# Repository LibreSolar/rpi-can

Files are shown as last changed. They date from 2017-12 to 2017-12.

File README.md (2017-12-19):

# Libre Solar CAN interface for Raspberry Pi (Zero W)

**Caution:** Developed using nightly build of KiCAD because of several nice features. Unfortunately, the files are not compatible with the current stable version, but a new compatible stable release (v5) of KiCad is expected soon.

## CAN to Wifi Gateway

This interface PCB allows to read data from the CAN bus connecting the Libre Solar components. So the Raspberry Pi can be used as a gateway to IoT applications and energy monitoring (e.g. using Open Energy Monitor).

The pin header is compatible with all Raspberry Pi models, but the size is especially suited for the Raspberry Pi Zero W.

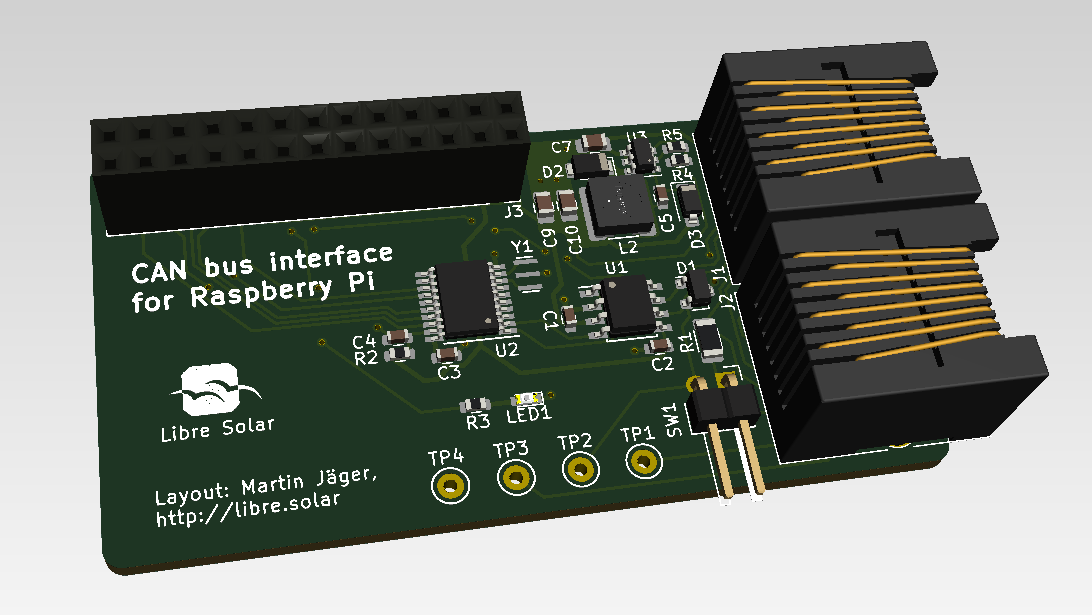
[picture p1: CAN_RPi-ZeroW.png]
Raspberry Pi CAN interface PCB


## Features:
- CAN interface via SPI using MCP2515 controller and TJA1042T/3 transceiver
- Power supply of Raspberry Pi via bus connector (RJ45)
- CAN transceiver standby connected to GPIO 24 (low power consumption mode possible)
- LED on GPIO 22 for custom status information

## Installation

Make sure to install the latest Raspbian onto your Raspberry Pi and connecto to it via SSH.

In order to activate the MCP2515 CAN controller, add the following lines to the file */boot/config.txt*:

```
# MCP 2515 CAN controller
dtparam=spi=on
dtoverlay=mcp2515-can0,oscillator=8000000,interrupt=25
```

Other guides for CAN on Raspberry Pi still suggest to add a line *dtoverlay=spi-bcm2835-overlay*. This is not true anymore, as Raspbian loads the BCM2835 SPI driver automatically.

Bring the interface up with the following command (change bitrate according to your needs):

```
sudo ip link set can0 up type can bitrate 250000
```

Now you should be able to send some test messages with *cansend* or watch messages on the bus:

```
candump can0
```

If something went wrong, try the following command to get some information about the CAN interface:

```
ip -s -d link show can0
```

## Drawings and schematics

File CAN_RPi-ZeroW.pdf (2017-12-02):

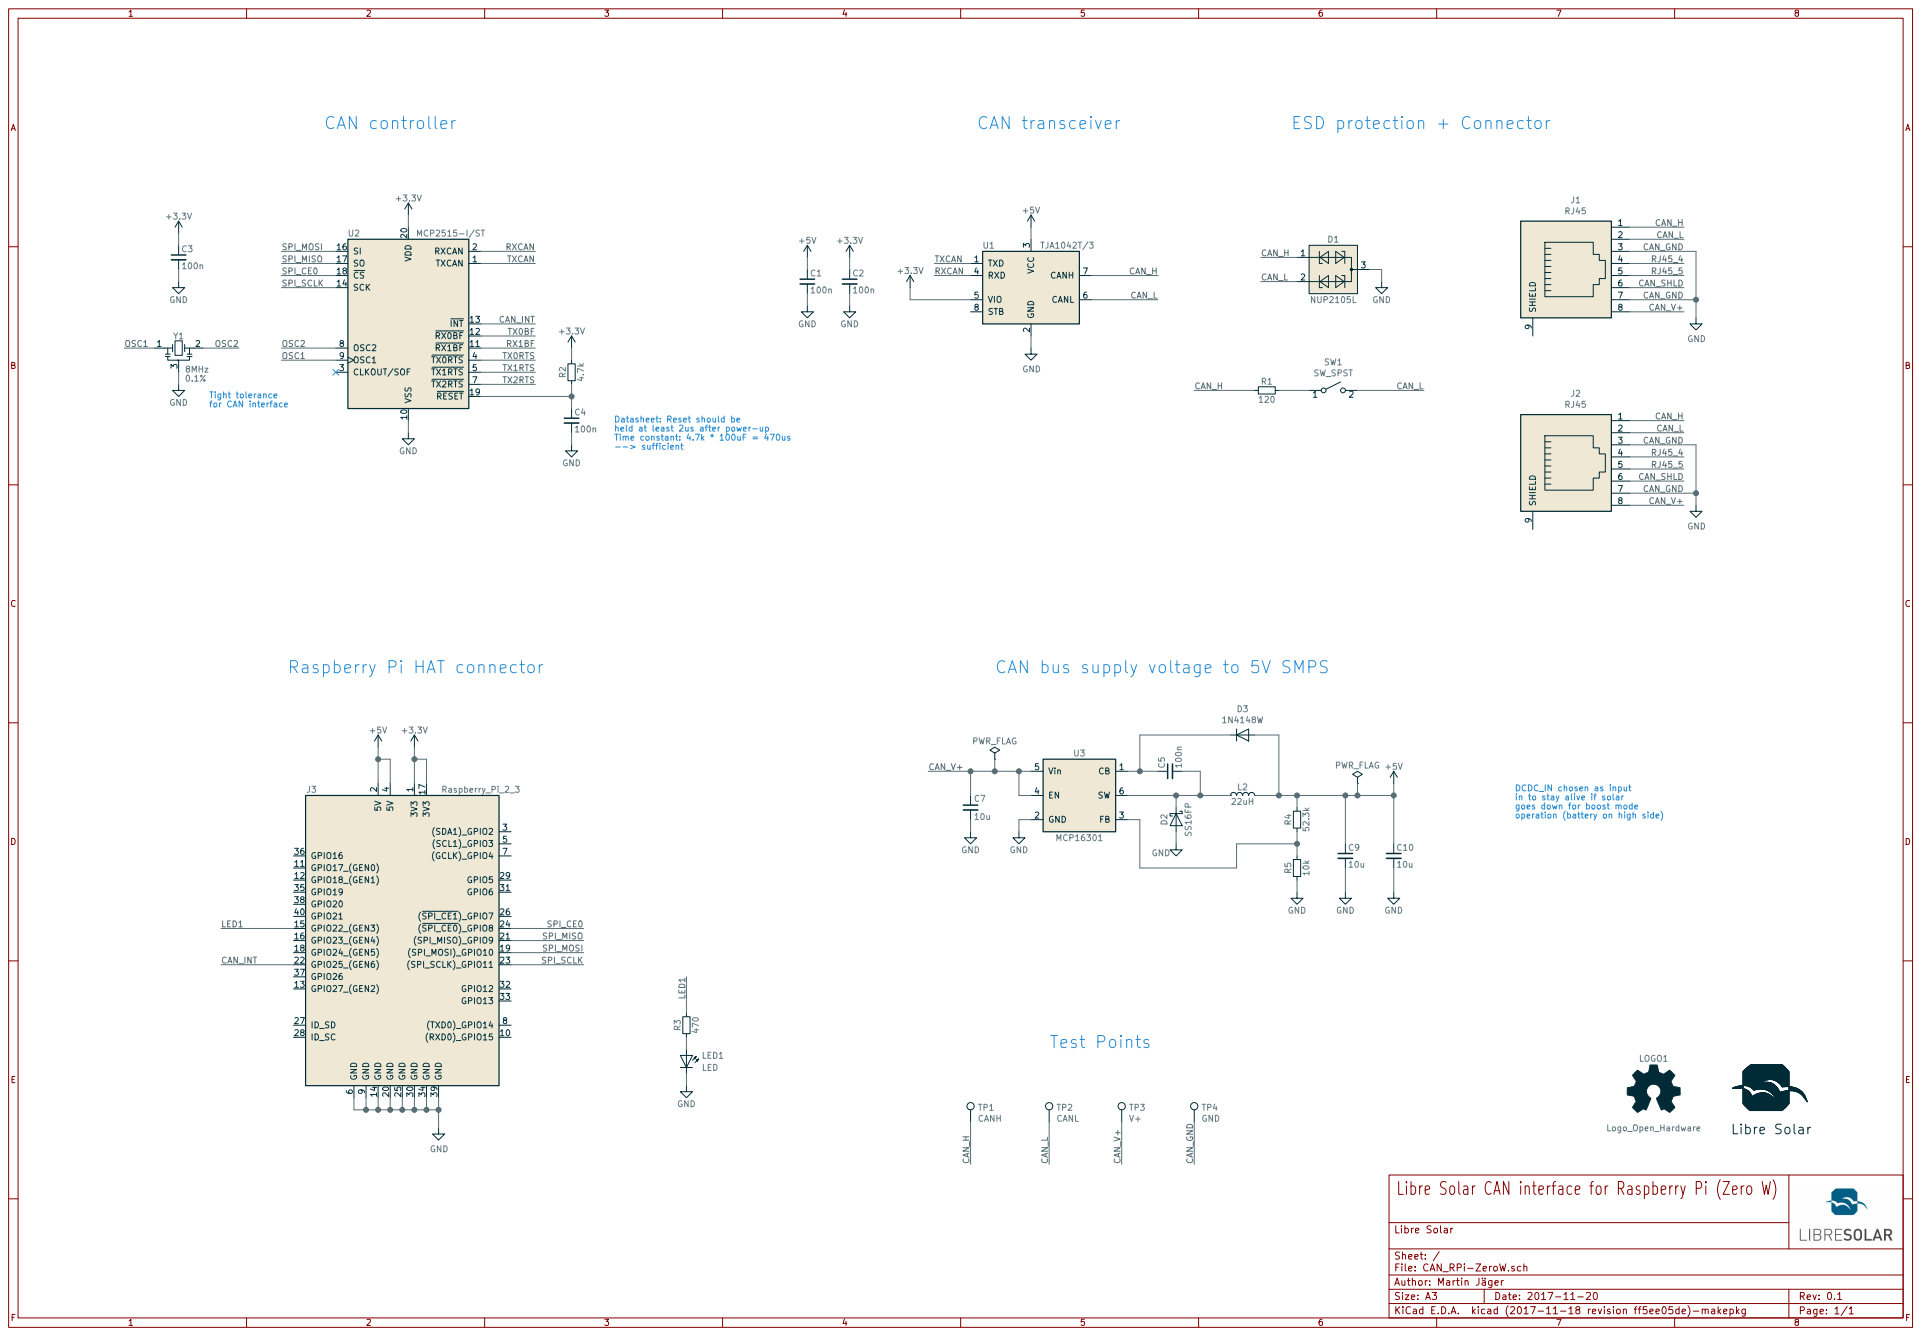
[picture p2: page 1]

3 RXD 4 VIO 5 CANL 6 CANH 7 STB 8 U1 TJA1042T/3 +5V +3.3V GND GND GND

held at least 2us after power-up Time constant: 4.7k * 100uF = 470us

+5V Raspberry Pi HAT connector

PWR_FLAG CAN bus supply voltage to 5V SMPS

DCDC_IN chosen as input
in to stay alive if solar
goes down for boost mode
operation (battery on high side)

Libre Solar CAN interface for Raspberry Pi (Zero W)

File: CAN_RPi-ZeroW.sch Sheet: / Libre Solar Author: Martin Jäger

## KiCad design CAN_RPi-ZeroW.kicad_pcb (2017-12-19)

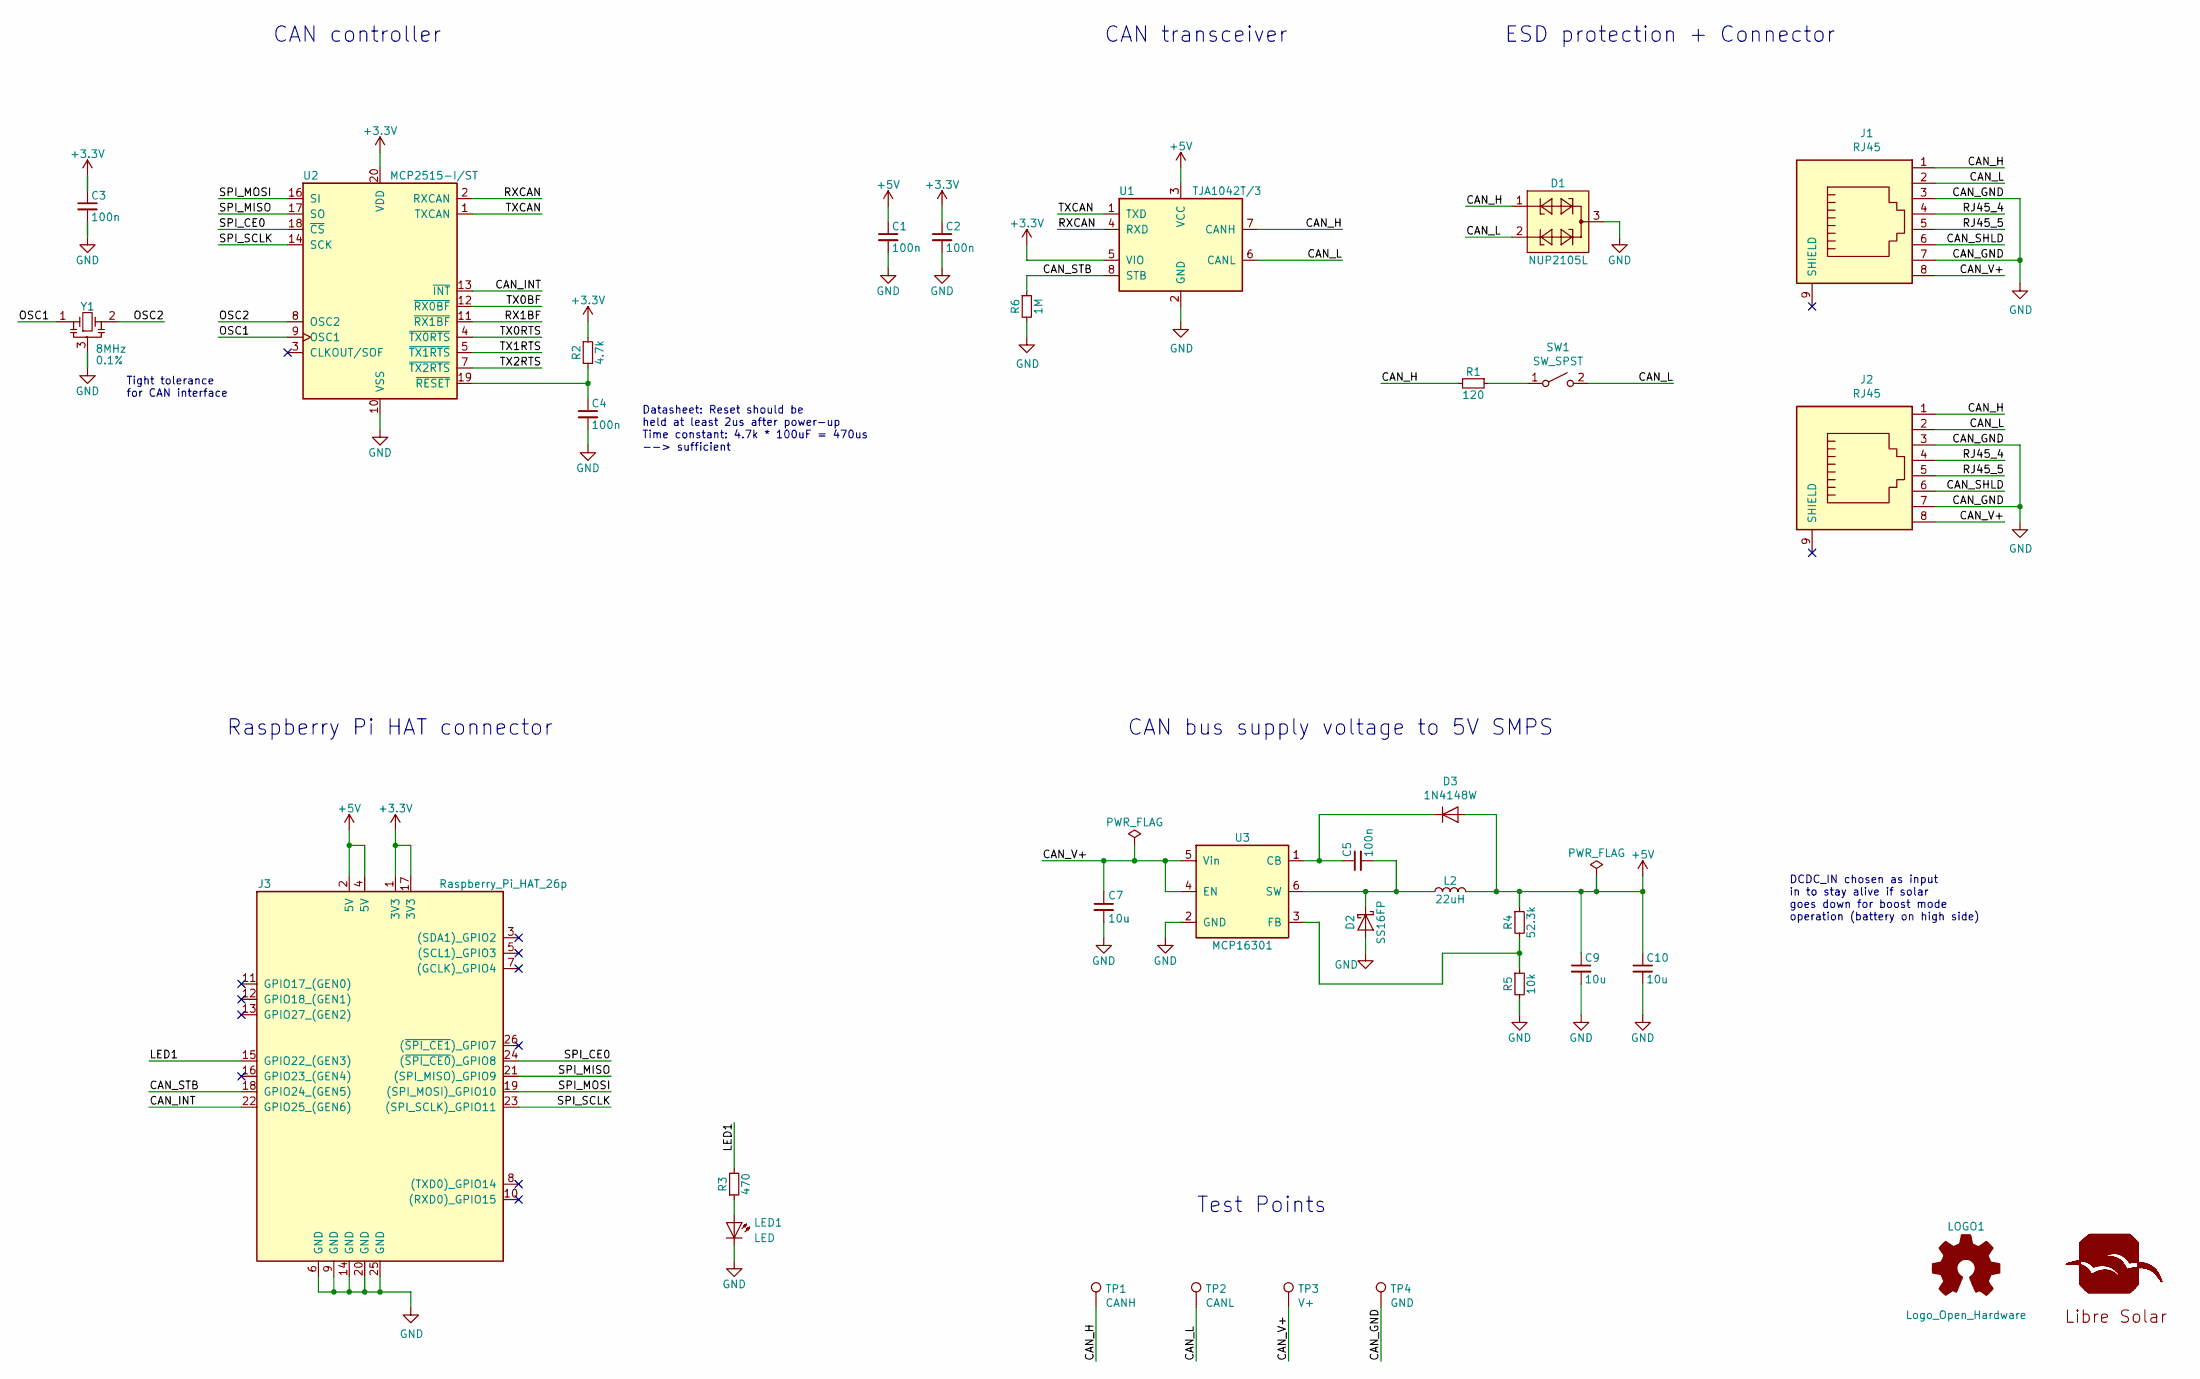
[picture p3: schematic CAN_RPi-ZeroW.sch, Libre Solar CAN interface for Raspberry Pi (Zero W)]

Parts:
C1, C2, C3, C4, C5: 100n; C_0603_1608; PartNumber GRM188R71H104KA93D
C7, C9, C10: 10u; C_0805_2012; PartNumber GRM21BR61E106KA73L
D1: NUP2105L; SOT-23; PartNumber NUP2105LT1G
D2: SS16FP; D_PowerDI-123; PartNumber SS16FP
D3: 1N4148W; D_SOD-123
J1, J2: RJ45; RJ45_8P8C
J3: Raspberry_Pi_HAT_26p; Socket_Strip_Straight_2x13_Pitch2.54mm
L2: 22uH; L_WE-TPC-4818; PartNumber SRR5028-470Y
LED1: LED; LED_0603
LOGO1: Logo_Open_Hardware; OSHW-Logo2_9.8x8mm_SilkScreen
N1: LIBRESOLAR_LOGO
R1: 120; R_1206_3216; PartNumber RC1206FR-07120RL
R2: 4.7k; R_0603_1608; PartNumber RC0603FR-074K7L
R3: 470; R_0603_1608; PartNumber RC0603FR-07470RL
R4: 52.3k; R_0603_1608; PartNumber RC0603FR-0752K3L
R5: 10k; R_0603_1608; PartNumber RC0603FR-0710KL
R6: 1M; R_0603_1608; PartNumber RC0603FR-071ML
SW1: SW_SPST; Pin_Header_Angled_1x02_Pitch2.54mm
TP1: CANH; Test_Point_Keystone_5000-5004_Miniature
TP2: CANL; Test_Point_Keystone_5000-5004_Miniature
TP3: V+; Test_Point_Keystone_5000-5004_Miniature
TP4: GND; Test_Point_Keystone_5000-5004_Miniature
U1: TJA1042T/3; SOIC-8_3.9x4.9mm_Pitch1.27mm
U2: MCP2515-I/ST; TSSOP-20_4.4x6.5mm_Pitch0.65mm
U3: MCP16301; SOT-23-6; PartNumber MCP16301
Y1: 8MHz; Resonator_Murata_CSTCE; Tolerance 0.1%; PartNumber CSTCE8M00G15C99-R0

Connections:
+3V3: C2.1, C3.1, J3.1 (3V3), J3.17 (3V3), R2.1, U1.5 (VIO), U2.20 (VDD)
+5V: C1.1, C9.1, C10.1, D3.2 (A), J3.2 (5V), J3.4 (5V), L2.2, R4.1, U1.3 (VCC)
/CAN_H: D1.1, J1.1, J2.1, R1.2, TP1.1, U1.7 (CANH)
/CAN_INT: J3.22 (GPIO25_(GEN6)), U2.13 (~INT)
/CAN_L: D1.2, J1.2, J2.2, SW1.2 (B), TP2.1, U1.6 (CANL)
/CAN_SHLD: J1.6, J2.6
/CAN_STB: J3.18 (GPIO24_(GEN5)), R6.1, U1.8 (STB)
/CAN_V+: C7.1, J1.8, J2.8, TP3.1, U3.4 (EN), U3.5 (Vin)
/LED1: J3.15 (GPIO22_(GEN3)), R3.2
/OSC1: U2.9 (OSC1), Y1.1
/OSC2: U2.8 (OSC2), Y1.2
/RJ45_4: J1.4, J2.4
/RJ45_5: J1.5, J2.5
/RX1BF: U2.11 (~RX1BF)
/RXCAN: U1.4 (RXD), U2.2 (RXCAN)
/SPI_CE0: J3.24 ((~SPI_CE0~)_GPIO8), U2.18 (~CS)
/SPI_MISO: J3.21 ((SPI_MISO)_GPIO9), U2.17 (SO)
/SPI_MOSI: J3.19 ((SPI_MOSI)_GPIO10), U2.16 (SI)
/SPI_SCLK: J3.23 ((SPI_SCLK)_GPIO11), U2.14 (SCK)
/TX0BF: U2.12 (~RX0BF)
/TX0RTS: U2.4 (~TX0RTS)
/TX1RTS: U2.5 (~TX1RTS)
/TX2RTS: U2.7 (~TX2RTS)
/TXCAN: U1.1 (TXD), U2.1 (TXCAN)
GND: C1.2, C2.2, C3.2, C4.2, C7.2, C9.2, C10.2, D1.3, D2.2 (A), J1.3, J1.7, J2.3, J2.7, J3.6 (GND), J3.9 (GND), J3.14 (GND), J3.20 (GND), J3.25 (GND), LED1.1 (K), R5.2, R6.2, TP4.1, U1.2 (GND), U2.10 (VSS), U3.2 (GND), Y1.3
unnamed: C4.1, R2.2, U2.19 (~RESET)
unnamed: C5.1, D3.1 (K), U3.1 (CB)
unnamed: C5.2, D2.1 (K), L2.1, U3.6 (SW)
unnamed: LED1.2 (A), R3.1
unnamed: R1.1, SW1.1 (A)
unnamed: R4.2, R5.1, U3.3 (FB)

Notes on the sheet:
Tight tolerance for CAN interface
CAN bus supply voltage to 5V SMPS
DCDC_IN chosen as input in to stay alive if solar goes down for boost mode operation (battery on high side)
Datasheet: Reset should be held at least 2us after power-up Time constant: 4.7k * 100uF = 470us --> sufficient
Raspberry Pi HAT connector
Test Points
CAN controller
CAN transceiver
ESD protection + Connector

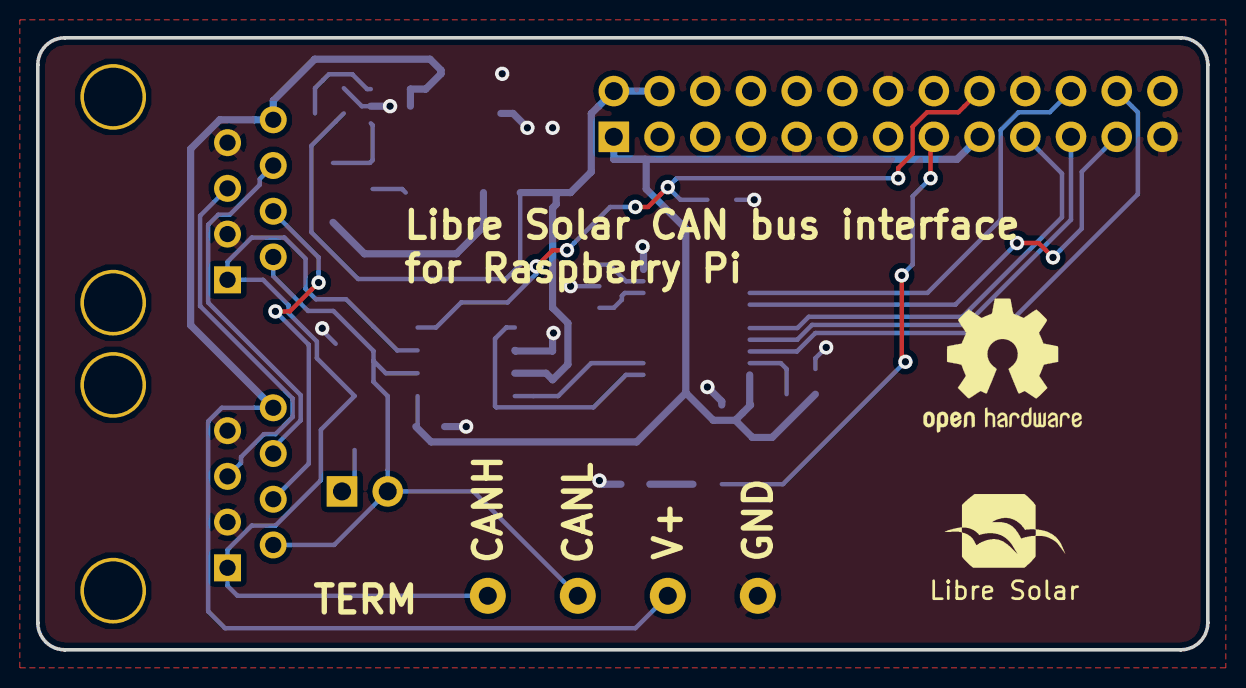
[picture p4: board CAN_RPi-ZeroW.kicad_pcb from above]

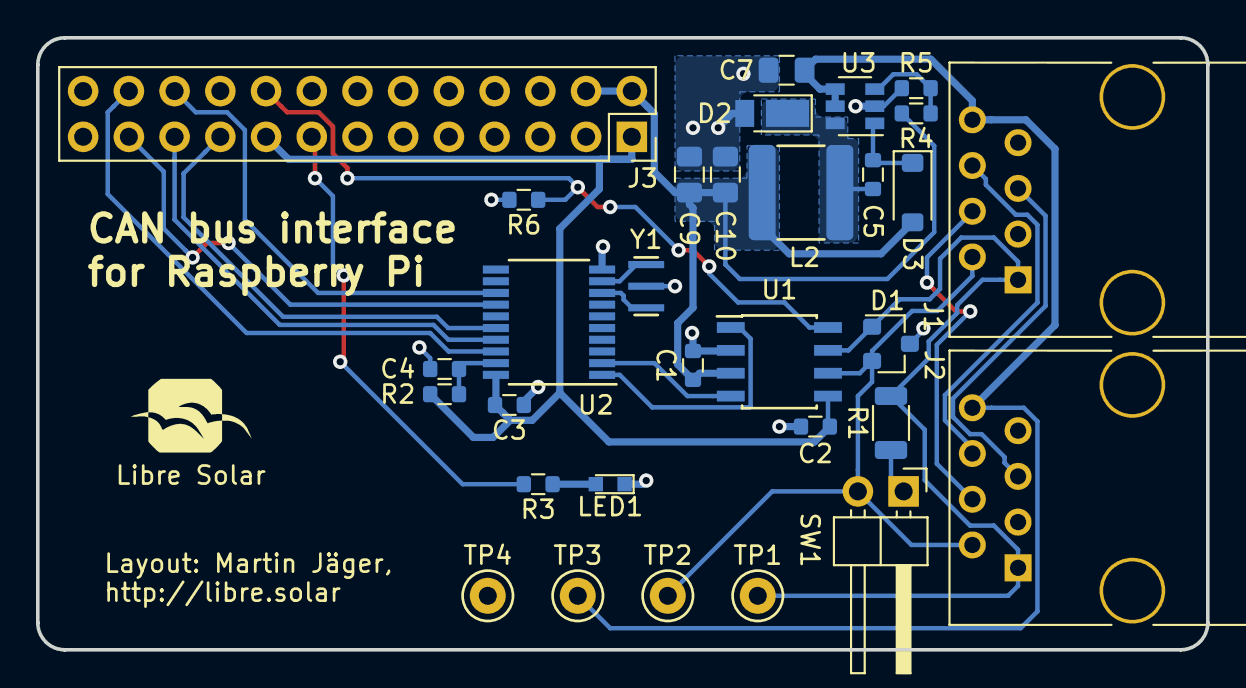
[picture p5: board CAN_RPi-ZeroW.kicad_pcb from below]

Board: 2 copper layers, 65.0 x 34.0 mm, 34 parts (32 on the bottom side), 26 nets.

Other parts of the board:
N1#2: LIBRESOLAR_LOGO

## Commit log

2017-12-19 PCB errors corrected and short installation guide added to README.md
    Corrected errors:
    - Pin header instead of socket strip used --> wrong pin layout of Raspi connector
    - STB pin of transceiver not connected --> sending of messages was not possible
    Now, small 26 pin connector is used instead of full 40 pin RPi HAT connector.
    [CAN_RPi-ZeroW.kicad_pcb, CAN_RPi-ZeroW.sch]
2017-12-19 Pull-down resistor for transceiver STB pin added.
    [CAN_RPi-ZeroW.kicad_pcb, CAN_RPi-ZeroW.sch]
